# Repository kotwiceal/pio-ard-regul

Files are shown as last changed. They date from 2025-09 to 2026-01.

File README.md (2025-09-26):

## Описание
---
Проект `PlatformIO` для реализации регулятора давления на основе микроконтроллера `Arduino Uno R3`.
#### Программная часть
---
Программа [[src/main.cpp]] реализована для двухканального управления *клапан-датчик давления* с возможностью расширения размерности.

 Управление микроконтроллера выполняется через последовательный `COM` порт с использованием `API` для среды `MATLAB` [[ardreg.m]]. 
 Примеры использования содержатся в файле [[ses.m]].

```octave
% инициализация экземпляра класса `ardreg` с указанием подключенного последовательного порта `COM4` 
mcu = ardreg('COM4');
```

```octave
% инициализция регулятора канала `0` с пороговой амплитудой сигнала с АЦП `threshold=300`, невязкой `discrepancy=50` и задержкой между изменением состояния клапана `deadtime=100` (величины задаются в отчетах)
mcu = mcu.control(0,true,threshold=300,discrepancy=50,deadtime=100);
```

```octave
% инициализация двух регуляторов: каналы `0` и `1`
mcu = mcu.control(0,true,threshold=300,discrepancy=50,deadtime=100);
mcu = mcu.control(1,true,threshold=500,discrepancy=100,deadtime=100);
```

```octave
% остановка регулятора
mcu = mcu.control(0,false);
```

```octave
% мониторинг управления
mcu.monitor(channel=[0,1]) % press `ESC` key to safely terminate loop
```

```octave
% управление состоянием клапана
channel = 0; channel = 0 | 1
state = 1; % state = 0 (закрыть) | 1 (открыть)
mcu.write('valve', channel, state);
```

> [!danger]
> При использовании метода `monitor()`, чтобы выйти из бесконечного цикла реализована функция обратного вызова, срабатывающая по нажатию клавиши `Ecs`, когда `MATLAB` фигура находится в выделенном состоянии. Использование прерывания цикла сочетанием клавиш `Ctrl+C` может повлиять на транзакцию пакетов с микроконтроллером, в этом случае необходимо заново инициализировать объект `ardreg`.
##### Аппаратная часть
---
Используются датчики давления с униполярным аналоговым выходом 0-5В, питание постоянным напряжением 5В.
Оцифровка сигнала давления выполняется АЦП микроконтроллера через мультиплексор `HP4067`.
Коммутация электромагнитных клапанов производится через твердотельные реле, срабатывающие по фронту логического сигнала.
В микроконтроллере реализованы несколько подходов управления:
1. `FIR`
2. $|pressure-threshold|<discrepancy$

Активным алгоритмом управления является 2-ой. Чтобы избежать залипание клапана используется таймер, отчитывающий моменты смены состояния, который задается параметром `deadtime`.

> [!important] Твердотельная модель корпуса для электроники выполнена в среде Компас 3D
> - [[box-ground.m3d]]
> - [[box-cap.m3d]]
> - [[box-assembly.a3d]]

##### Порядок работы
1. Включение микроконтроллера через блок питания
    - инициализация АЦП в режиме непрерывного опроса
    - каналы упрвления и цифровых выходов в пассивном состоянии
2. Подключение микроконтроллера к ПК через USB
    - инициализация подключениея через `COM` порт
    ```octave
    mcu = ardreg('COM4');
    ```
    - конфигурировать работу микроконтроллера через методы `mcu.control()` и/или `mcu.write()`

> [!important] Если микроконтролер использует другой порт, выполнить вызов фунции `serialportlist` и определить порт устройства.

> [!important] После конфигурации микроконтроллера можно разорвать соединение `COM` порта, однако при отключении питания микроконтроллера необходимо заново его проиницилизировать.

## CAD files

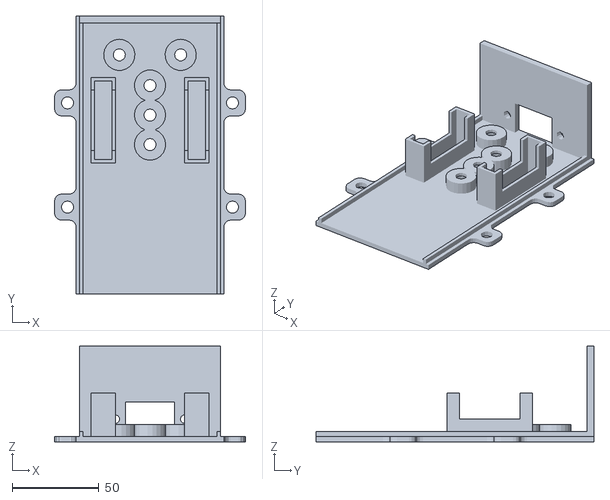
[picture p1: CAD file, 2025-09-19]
cad/box-ground.stl
110.0 x 160.0 x 55.0

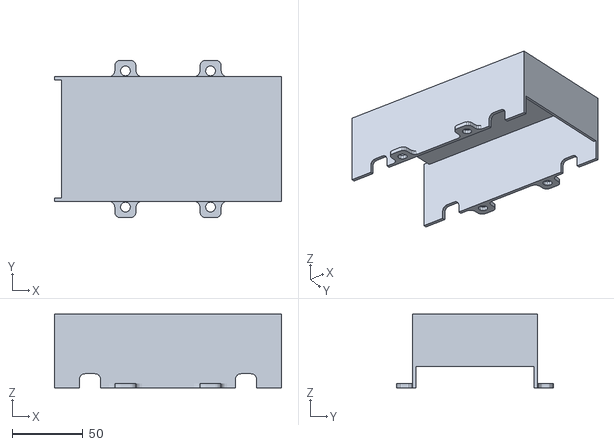
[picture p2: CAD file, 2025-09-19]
cad/box-cap.stl
160.0 x 111.0 x 52.0

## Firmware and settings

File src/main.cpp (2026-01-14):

#include <Arduino.h>

#define BOARDRATE 115200

// define FSM
#define DIGITAL_OUT_WRITE 1
#define DIGITAL_OUT_READ 2
#define ANALOG_READ 3
#define DIGITAL_IN_READ 4
#define REGULATOR_ENABLE 5
#define REGULATOR_COEF_WRITE 6
#define REGULATOR_COEF_READ 7
#define REGULATOR_THRESHOLD_X_WRITE 8
#define REGULATOR_THRESHOLD_X_READ 9
#define REGULATOR_DISCREPANCY_X_WRITE 10
#define REGULATOR_DISCREPANCY_X_READ 11
#define REGULATOR_THRESHOLD_Y_WRITE 12
#define REGULATOR_THRESHOLD_Y_READ 13
#define REGULATOR_X_READ 14
#define REGULATOR_Y_READ 15
#define REGULATOR_FIR_READ 16
#define REGULATOR_NUMBER 17
#define REGULATOR_BUFFER_LENGTH 18
#define REGULATOR_DEADTIME_READ 19
#define REGULATOR_DEADTIME_WRITE 20
#define VALVE_READ 21
#define VALVE_WRITE 22
const int buffbits = 4;
char buffer[buffbits];
int bytesRead = 0;
int8_t command = 0, address = 0;
int16_t data = 0;

// define general purpose input digital pins
const uint8_t gpin = 3;
int8_t gpinMask[gpin] = {8, 9, 10};
bool gpinValue[gpin] = {0, 0, 0};

// define general purpose output digital pins
const uint8_t gpout = 4;
uint8_t gpoutMask[gpout] = {4, 5, 6, 7};
bool gpoutValue[gpout] = {0, 0, 0, 0};

// define regulator parameters
const uint8_t reg_num = 2;
const uint8_t reg_buf_len = 4;
uint8_t reg_ptr = 0;
uint16_t reg_buf[reg_num][reg_buf_len];
int16_t reg_coef[reg_num][reg_buf_len];
uint8_t reg_mask[reg_buf_len];
uint16_t reg_thresh_x[reg_num];
int16_t reg_thresh_y[reg_num];
int16_t reg_fir_res[reg_num];
uint16_t reg_disc_x[reg_num];
bool reg_en[reg_num];

// define digital pins of regulator
uint8_t pinControlMask[reg_num] = {12, 13};
bool pinControlValue[reg_num] = {0, 0};

// define analog pins of regulator
uint8_t pinSignalMask[reg_num] = {A0, A1};
uint16_t pinSignalValue[reg_num] = {0, 0};

// define multiplexer mask pin
const uint8_t pinMultBits = 1;
uint8_t pinMultAddr[pinMultBits] = {2};

// define timer of trigger schmitt
uint32_t time[reg_num], deadtime[reg_num];
bool trigger[reg_num];

float fir(uint16_t x[], int16_t coef[], uint8_t mask[], const uint8_t len) {
	float y = 0;
	for (uint8_t i = 0; i < len; i++) {
		y = y + x[i]*coef[mask[i]];
	}
	return y;
}

void regulator() {
	// circular shift
	for (uint8_t i = 0; i < reg_buf_len; i++) {
    if ((reg_ptr+i) < reg_buf_len) {
      reg_mask[reg_ptr+i] = i;
    } else {
      reg_mask[reg_ptr+i-reg_buf_len] = i;
    }
	}
	// consequence ADC acquisition
	for (uint8_t i = 0; i < reg_num; i++) {
		switch (i) {
			case 0:
				digitalWrite(pinMultAddr[0], LOW);
				break;
			case  1:
				digitalWrite(pinMultAddr[0], HIGH);
			default:
				break;
		}
		delay(10);
		pinSignalValue[i] = analogRead(pinSignalMask[i]);
		// accumulate buffer
		reg_buf[i][reg_ptr] = pinSignalValue[i];
		delay(1);
	};
	// circular increment
	if (reg_ptr == reg_buf_len - 1) {
		reg_ptr = 0;
	} else {
		reg_ptr = reg_ptr + 1;
	}
	for (uint8_t i = 0; i < reg_num; i++) {
		if (!trigger[i]) {
			pinControlValue[i] = !(int16_t(pinSignalValue[i] - reg_thresh_x[i]) > int16_t(reg_disc_x[i])) & reg_en[i];
			if (reg_en[i]) {
				digitalWrite(pinControlMask[i], pinControlValue[i]);
			}
			trigger[i] = true;
			time[i] = 0;
		} else {
			if (time[i] > deadtime[i]) {
				trigger[i] = false;
			}
		}
	};
}

void com() {
	// serial port
	if (Serial.available() > 0) {
		// read buffer
		bytesRead = Serial.readBytes(buffer, sizeof(buffer)); 
		if (bytesRead != buffbits) { 
			buffer[0] = 0;
			buffer[1] = 0;
			buffer[2] = 0;
			buffer[3] = 0;
			Serial.write(buffer, sizeof(buffer));
			Serial.flush();
			return;
		}

		// parse packet
		command = buffer[0];
		address = buffer[1];
		data = ((buffer[2] & 255) << 8) | (buffer[3] & 255);

		// FSM
		switch (command) {
			case DIGITAL_IN_READ:
				gpinValue[address] = digitalRead(gpinMask[address]);
				data = gpinValue[address];
				break;
			case DIGITAL_OUT_WRITE:
				gpoutValue[address] = bool(data);
				digitalWrite(address, gpoutValue[address]);
				break;
			case DIGITAL_OUT_READ:
				data = gpoutValue[address];
				break;
			case ANALOG_READ:
				data = pinSignalValue[address];
				break;
			case REGULATOR_ENABLE:
				reg_en[address] = bool(data);
				break;
			case REGULATOR_COEF_WRITE:
				reg_coef[address >> 4][address & 15] = data;
				break;
			case REGULATOR_COEF_READ:
				data = reg_coef[address >> 4][address & 15];
				break;
			case REGULATOR_THRESHOLD_X_WRITE:
				reg_thresh_x[address] = data;
				break;
			case REGULATOR_THRESHOLD_X_READ:
				data = reg_thresh_x[address];
				break;
			case REGULATOR_DISCREPANCY_X_WRITE:
				reg_disc_x[address] = data;
				break;
			case REGULATOR_DISCREPANCY_X_READ:
				data = reg_disc_x[address];
				break;
			case REGULATOR_THRESHOLD_Y_WRITE:
				reg_thresh_y[address] = data;
				break;
			case REGULATOR_THRESHOLD_Y_READ:
				data = reg_thresh_y[address];
				break;
			case REGULATOR_X_READ:
				data = pinSignalValue[address];
				break;
			case REGULATOR_Y_READ:
				data = pinControlValue[address];
				break;
			case REGULATOR_FIR_READ:
				data = reg_fir_res[address];
				break;
			case REGULATOR_NUMBER:
				data = int16_t(reg_num);
				break;
			case REGULATOR_BUFFER_LENGTH:
				data = int16_t(reg_buf_len);
				break;
			case REGULATOR_DEADTIME_READ:
				data = deadtime[address];	
				break;
			case REGULATOR_DEADTIME_WRITE:
				deadtime[address] = data;
				break;
			case VALVE_READ:
				pinControlValue[address] = digitalRead(pinControlMask[address]);
				data = pinControlValue[address];
				break;
			case VALVE_WRITE:
				pinControlValue[address] = data;
				digitalWrite(pinControlMask[address], pinControlValue[address]);
				break;
			default:
				break;
		}

		// split bits
		buffer[2] = (uint8_t) (data >> 8);
		buffer[3] = (uint8_t) (data);

		// transmit response
		Serial.write(buffer, sizeof(buffer));
		Serial.flush();
	}
}

void setup() {
	Serial.begin(BOARDRATE);
	Serial.setTimeout(5000);
	// initialize general purpose input digital pins
	for (int i = 0; i < gpin; i++) {pinMode(gpinMask[i], INPUT);}
	// initialize general purpose output digital pins
	for (int i = 0; i < gpout; i++) 
		{pinMode(gpoutMask[i], OUTPUT); digitalWrite(gpoutMask[i], gpoutValue[i]);}
	// iniitalize control output digital pins
	for (int i = 0; i < reg_num; i++) 
		{pinMode(pinControlMask[i], OUTPUT); digitalWrite(pinControlMask[i], pinControlValue[i]);}
	// initialize regulator
	for (uint8_t i = 0; i < reg_num; i++) {
		reg_thresh_x[i] = 0;
    	reg_thresh_y[i] = 0;
		reg_disc_x[i] = 0;
		reg_en[i] = false;
    	reg_fir_res[i] = 0;
		for (uint8_t j = 0; j < reg_buf_len; j++) {
      		reg_mask[j] = j;
			reg_buf[i][j] = 0;
			reg_coef[i][j] = 0;
		}
	}
	// initialize timer
	for (uint8_t i = 0; i < reg_num; i++) {
		time[i] = 0;
		deadtime[i] = 100;
		trigger[i] = false;
	}
	// initialize multiplexer address pins
	for (uint8_t i = 0; i < pinMultBits; i++) {
		pinMode(pinMultAddr[i], OUTPUT);
		digitalWrite(pinMultAddr[i], LOW);
	}
}

void loop() {
	regulator();
	com();
	// update timers
	delay(1);
	for (uint8_t i = 0; i < reg_num; i++) {
		time[i] = time[i] + 1;
	}
}

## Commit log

2025-08-21 initialize project, implement `FIR` control, `UART` slave `FSM`
2025-09-19 design box, modify `monitor()` function, refactor docs
    [box-cap.stl, box-ground.stl]
2025-09-20 adds valve control functions/API, modify docs
2025-09-26 fix control/manual mode relay state
    [main.cpp]
2026-01-14 adds sensor read function
